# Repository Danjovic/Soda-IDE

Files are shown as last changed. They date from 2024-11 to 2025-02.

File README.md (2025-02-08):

# SODA IDE
Compact Flash Card Interface for MSX based on [SC729 RCBus Compact Flash Module]( https://smallcomputercentral.com/sc729-rcbus-compact-flash-module/) originally designed by [Tadeusz Pycio](http://www.vtsys.pl/interface-compact-flash/) and [Beer IDE 232](https://github.com/b3rendsh/msxdos2s) by b3rendsh 

## Printed circuit Boards:
### For Konami Case

#### Version 1
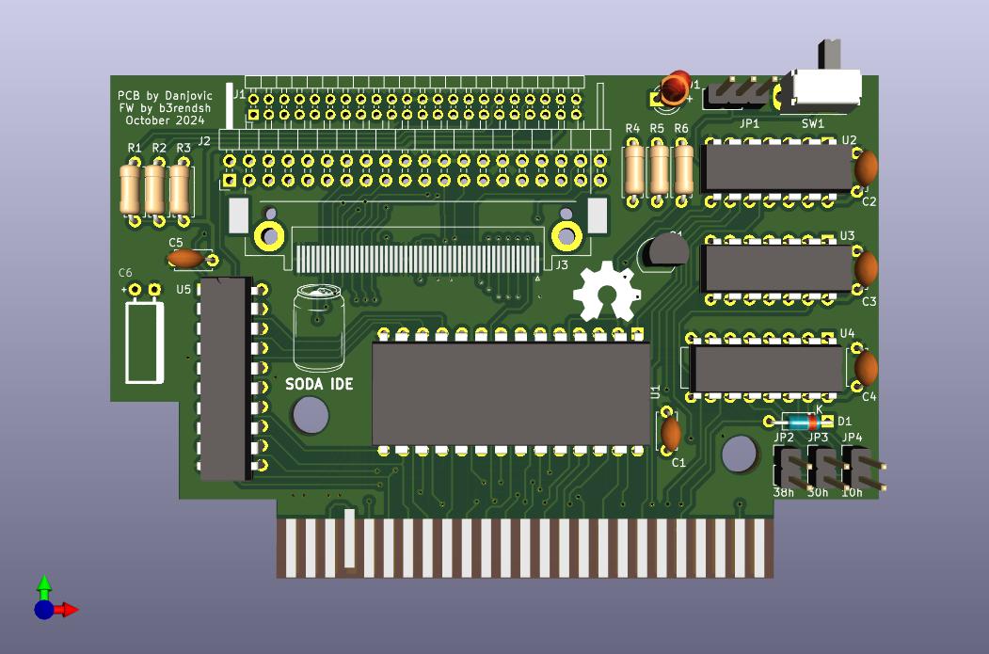
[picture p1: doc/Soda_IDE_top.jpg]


#### Version 2
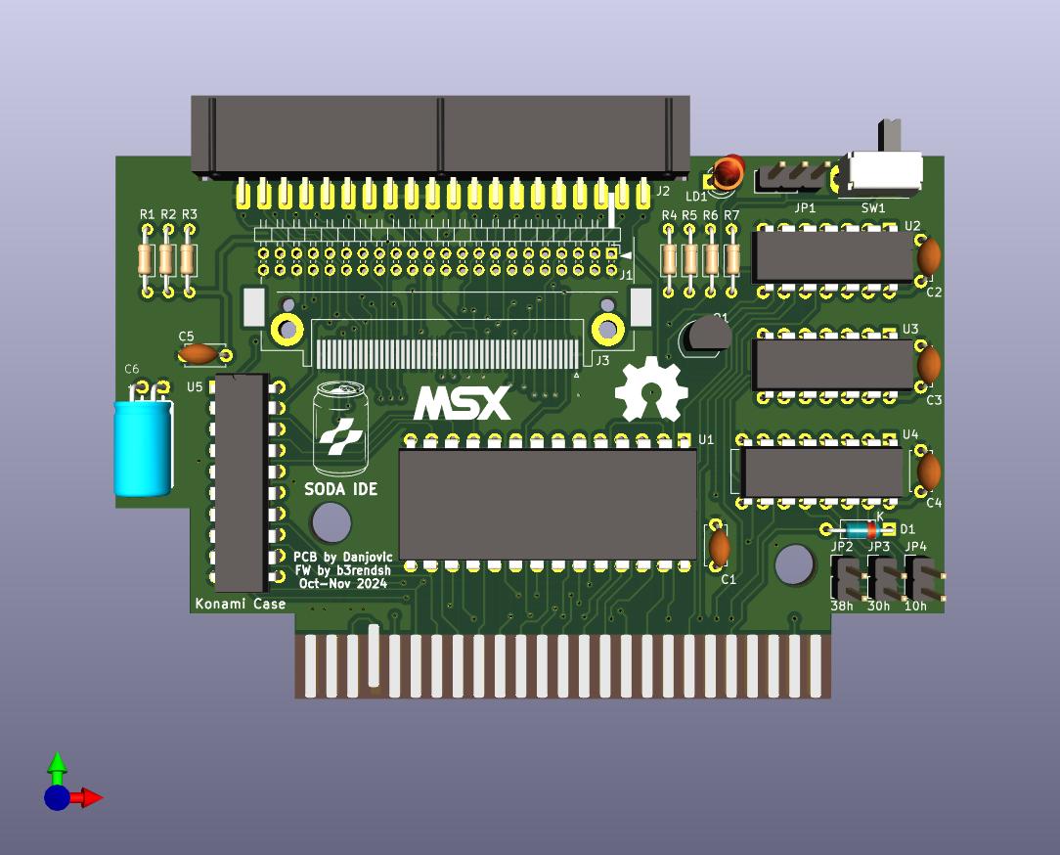
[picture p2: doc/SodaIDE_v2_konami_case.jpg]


### For Patola Case
#### Version 2
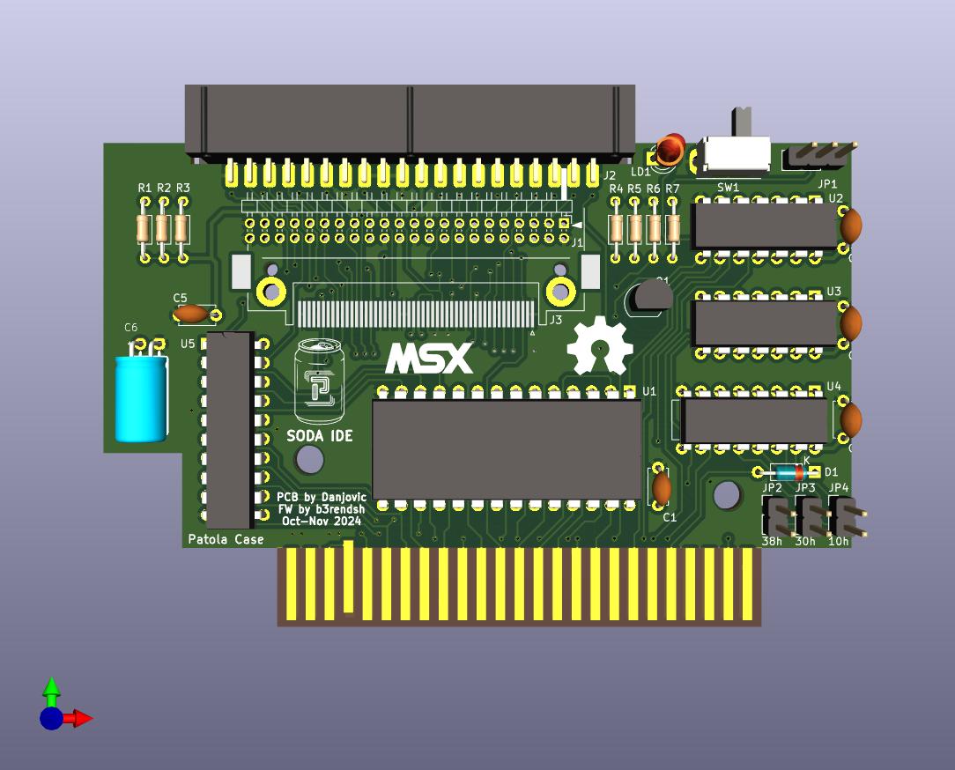
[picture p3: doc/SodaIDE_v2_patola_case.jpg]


### BILL OF MATERIALS

#### Semiconductors

| Reference | Value | Description |
|:---:|:---: |:--- |
|  U1 | 27C512 | EEPROM 64Kb x 8 (512kbits) |
|  U2 | 74HCT32  | TTL chip, can be either LS, HC or HCT |
|  U3 | 74HCT74  | TTL chip, can be either LS, HC or HCT |
|  U4 | 74HCT138 | TTL chip, can be either LS, HC or HCT |
|  U5 | 74HC245  | TTL chip, can be either LS, HC or HCT |
|  Q1 | BC548 | NPN transistor |
| LD1 | -- | Diameter 3.0mm, Red |
|  D1 | 1N4148 | Fast diode, Sillicon (alternatives 1N914) |

#### Capacitors

| Reference | Value | Description |
|:---:|:---: |:--- |
|C1,C2,C3,C4,C5| 100nF | Capacitor, Ceramic disc or Polyester |
|C6| 100uF/16V | Electrolytic Capacitor (preferrable low profile) |
		
#### Resistors		
| Reference | Value | Description |
|:---:|:---: |:--- |
| R1,R2,R3,R6 | 4K7 | Resistor, ¼ Watt | 
| R4 | 1K | Resistor, ¼ Watt | 
| R5 | 10K | Resistor, ¼ Watt | 
		
#### Miscellaneous		
| Reference | Value | Description |
|:---:|:---: |:--- |
|SW1	| -- | SPDT Switch, slide, right angle (reference OS102011MA1QN1) |
|CN1	| -- | Printed Circuit Board. Gerbers for Konami [V1](https://github.com/Danjovic/Soda-IDE/tree/main/hardware/V1/Gerber), [V2](https://github.com/Danjovic/Soda-IDE/tree/main/hardware/V2/SodaIDE_v2_konami_case/pcbway_production/2025-02-08-15-33-09), Patola [V2](https://github.com/Danjovic/Soda-IDE/tree/main/hardware/V2/SodaIDE_v2_patola_case/pcbway_production/2025-02-08-15-50-29) |
|JP1	| -- | Pin Header, 1x3 pin, pitch 2.54mm, straight (Vertical) |
|JP2,JP3,JP4 | -- | Pin Header, 1x2 pin, pitch 2.54mm, straight (Vertical) |

#### 44 pin CF adapter option		
| J1	|	Pin Header, 2x22 pin, pitch 2.0mm, right angle (Horizontal) |
|:---:| :--- |
		
#### 40 pin CF adapter option		
|J2	|	Pin Header, 2x20 pin, pitch 2.54mm, right angle (Horizontal)
|:---:| :--- |
		
#### CF Socket Option		
|J3	|	CF Card Connector (reference 3M_N7E50-E516xx-30)
|:---:| :--- |

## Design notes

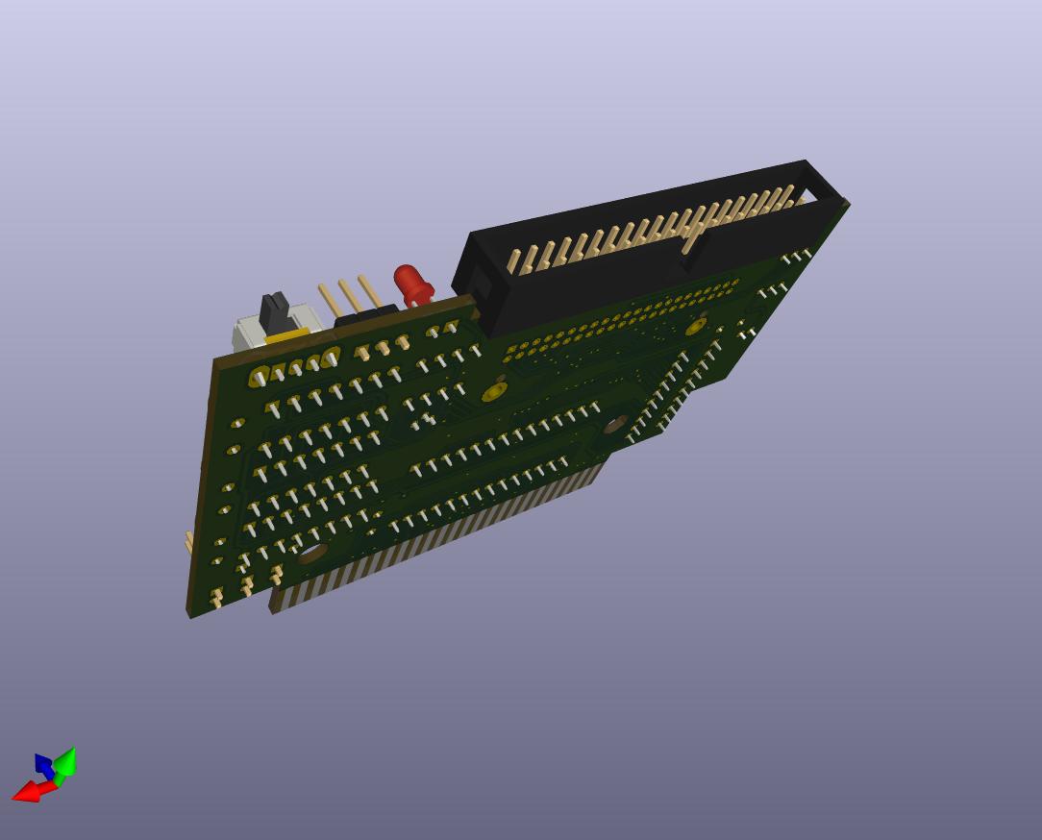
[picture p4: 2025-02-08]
doc/SodaIDE_v2_konami_case_rear.jpg

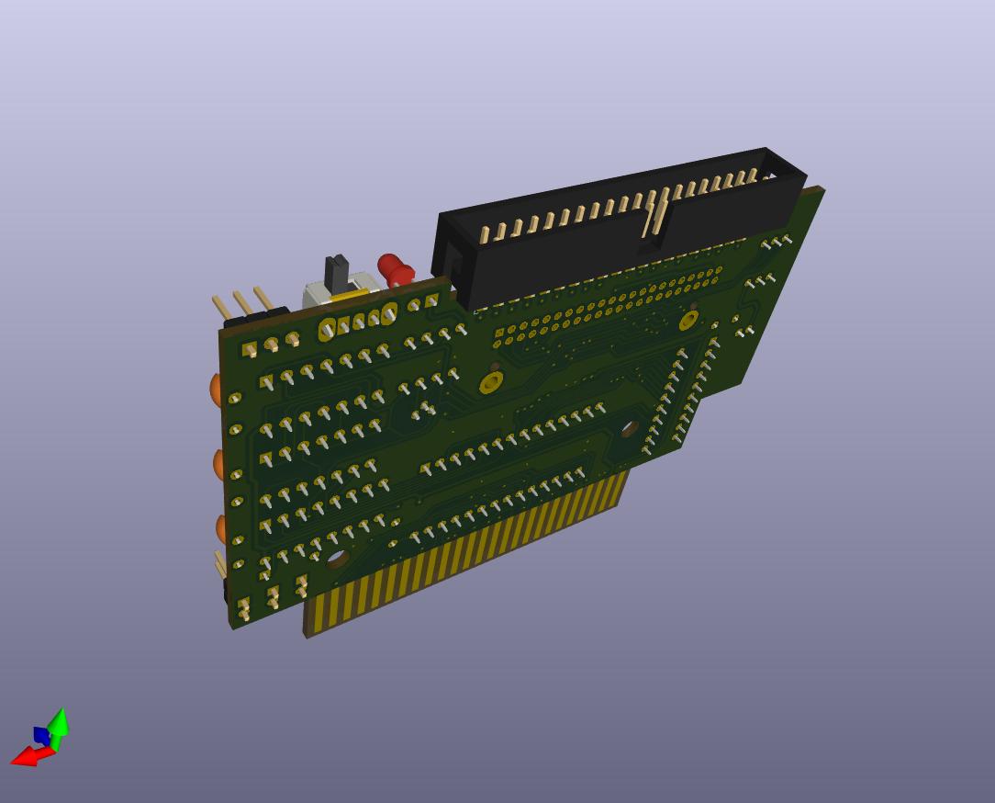
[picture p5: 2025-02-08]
doc/SodaIDE_v2_patola_case_rear.jpg

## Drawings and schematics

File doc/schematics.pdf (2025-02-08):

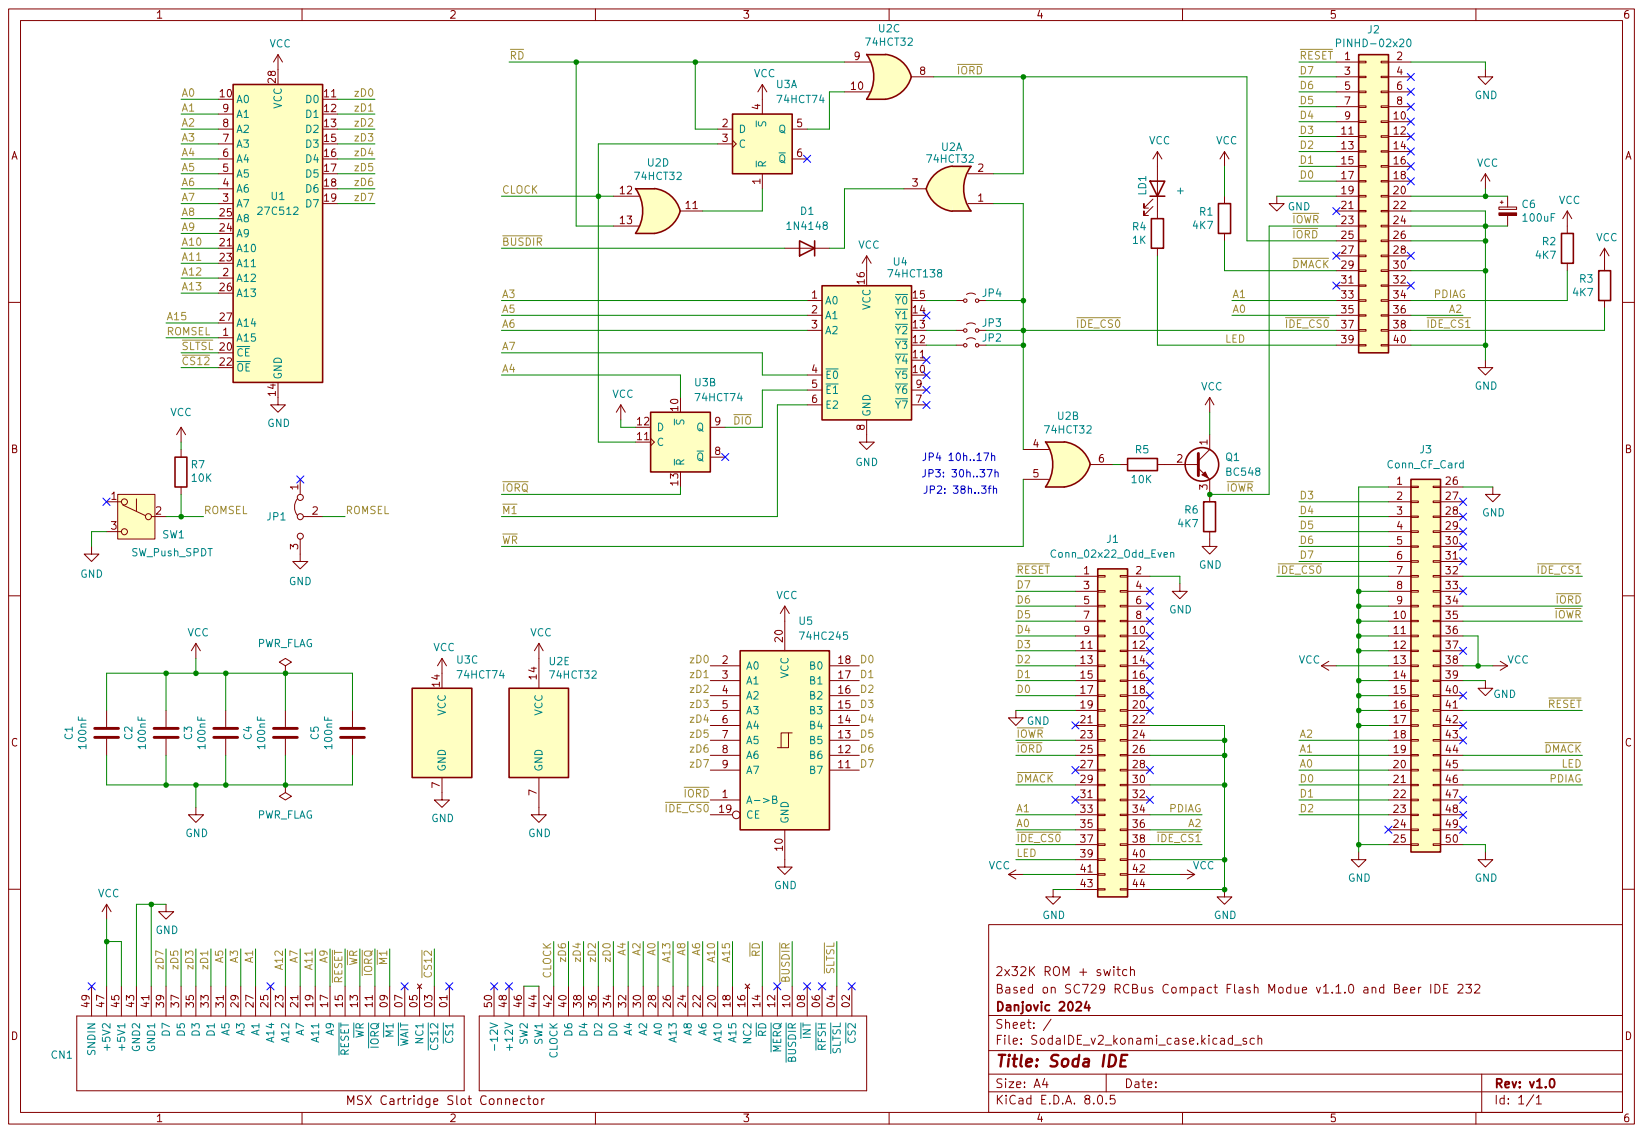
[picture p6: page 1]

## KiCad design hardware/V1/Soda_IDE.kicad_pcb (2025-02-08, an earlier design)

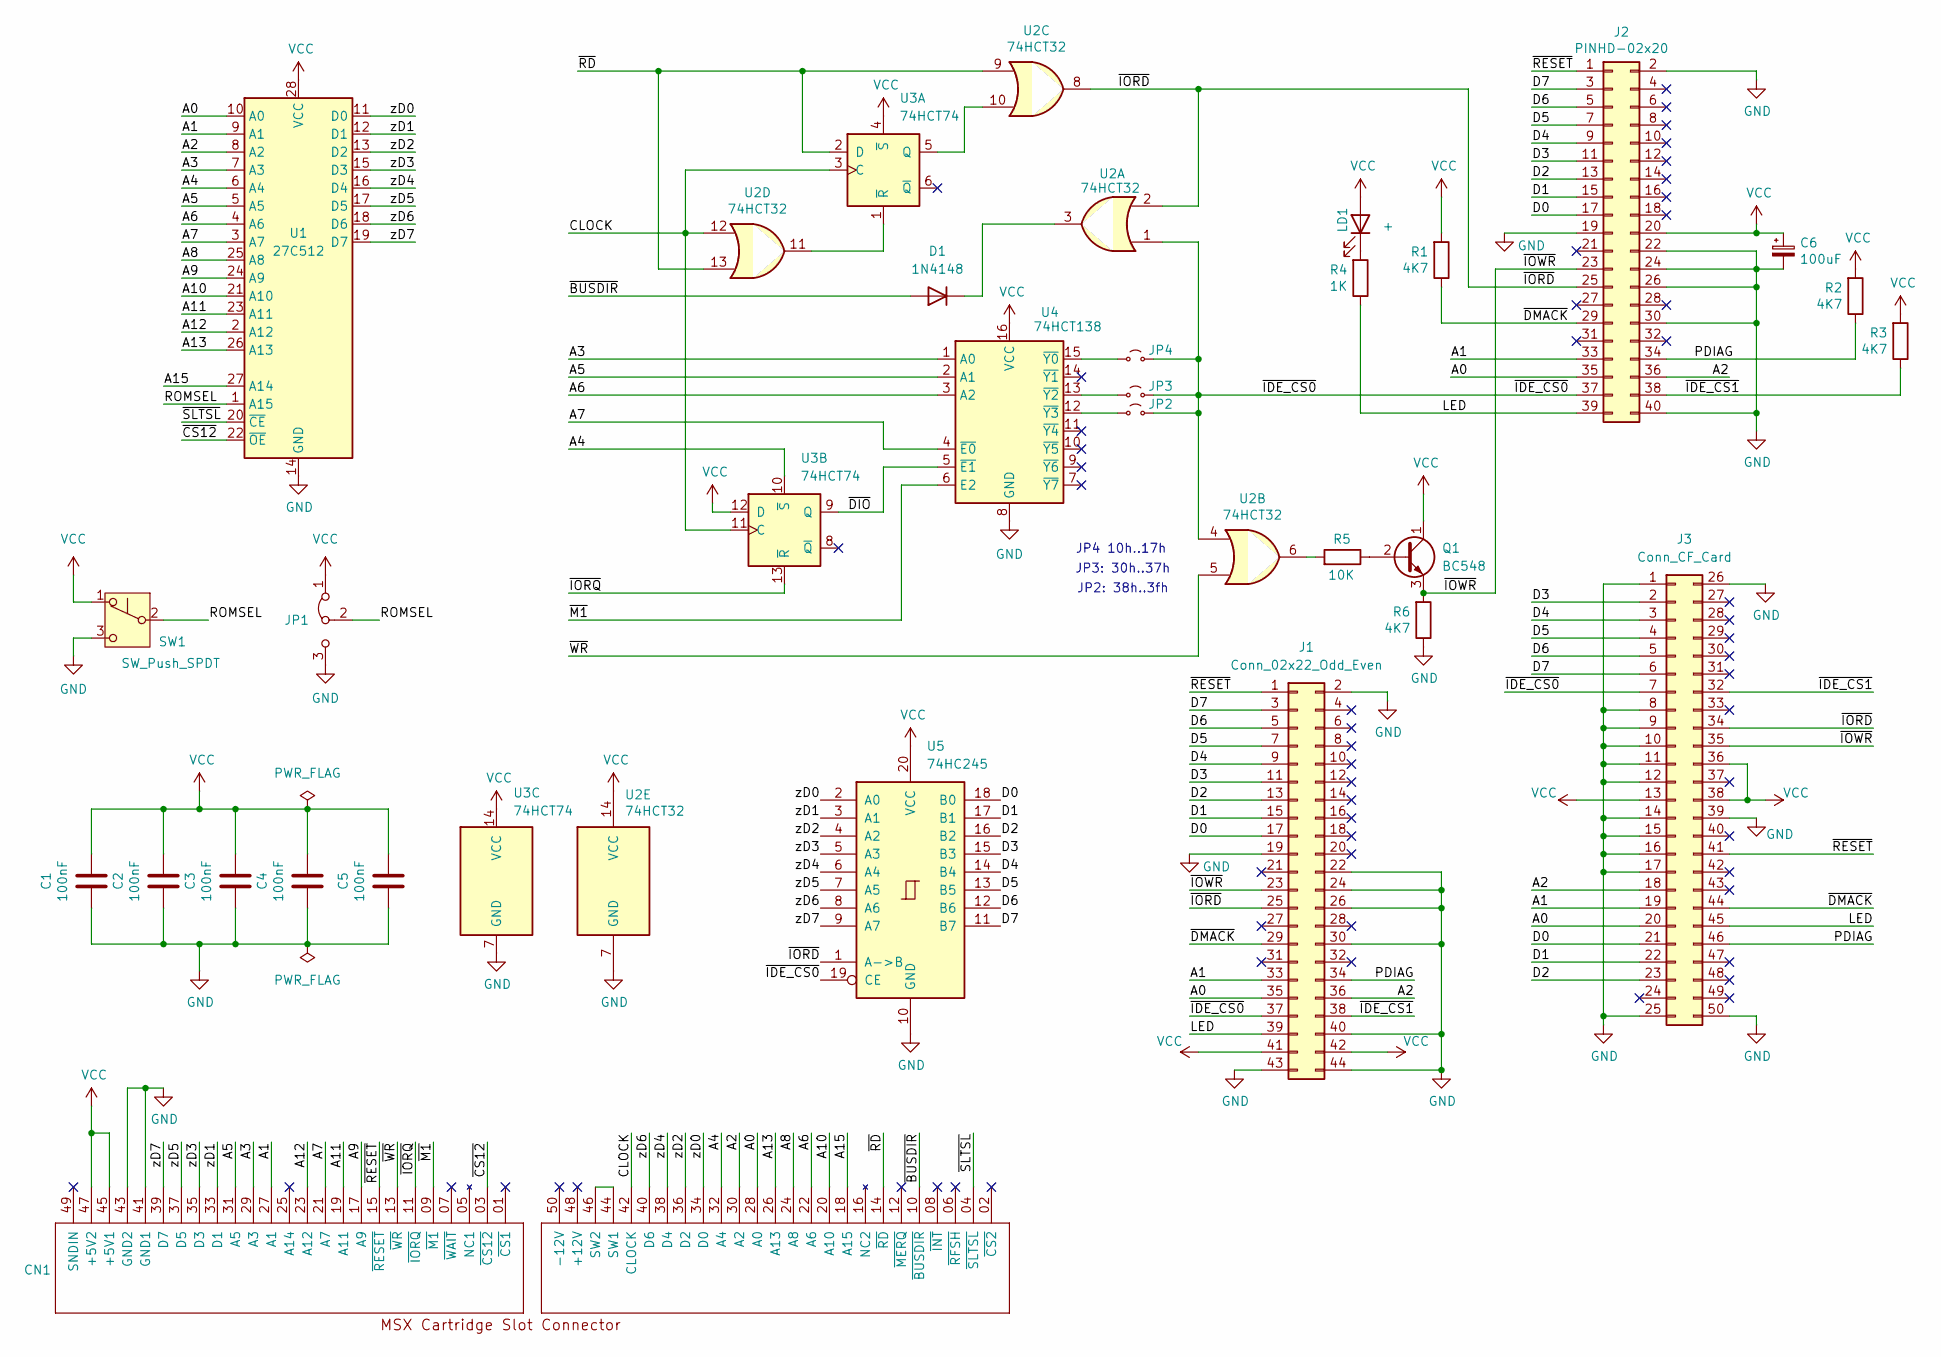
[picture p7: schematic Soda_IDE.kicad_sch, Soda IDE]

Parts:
C1, C2, C3, C4, C5: 100nF; C_Disc_D4.7mm_W2.5mm_P5.00mm
C6: 100uF; CP_lying
CN1: MSX_SLOT_CON; Cart_Konami
D1: 1N4148; D_DO-35_SOD27_P7.62mm_Horizontal
J1: Conn_02x22_Odd_Even; PinHeader_2x22_P2.00mm_Horizontal
J2: PINHD-02x20; PinHeader_2x20_P2.54mm_Horizontal
J3: Conn_CF_Card; CF-Card_3M_N7E50-E516xx-30
JP1: PIN_1x3; PinHeader_1x03_P2.54mm_Vertical
JP2, JP3, JP4: Jumper_2_Small_Open; PinHeader_1x02_P2.54mm_Vertical
LD1: +; LED_D3.0mm
Q1: BC548; TO-92_Inline
R1, R2, R3, R6: 4K7; R_Axial_DIN0207_L6.3mm_D2.5mm_P7.62mm_Horizontal
R4: 1K; R_Axial_DIN0207_L6.3mm_D2.5mm_P7.62mm_Horizontal
R5: 10K; R_Axial_DIN0207_L6.3mm_D2.5mm_P7.62mm_Horizontal
SW1: SW_Push_SPDT; SW_Slide_SPDT_Angled_CK_OS102011MA1Q
U1: 27C512; DIP-28_W15.24mm
U2: 74HCT32; DIP-14_W7.62mm
U3: 74HCT74; DIP-14_W7.62mm
U4: 74HCT138; DIP-16_W7.62mm
U5: 74HC245; DIP-20_W7.62mm

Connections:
/A0: CN1.28 (A0), J1.35, J2.35, J3.20, U1.10 (A0)
/A1: CN1.27 (A1), J1.33, J2.33, J3.19, U1.9 (A1)
/A2: CN1.30 (A2), J1.36, J2.36, J3.18, U1.8 (A2)
/A3: CN1.29 (A3), U1.7 (A3), U4.1 (A0)
/A4: CN1.32 (A4), U1.6 (A4), U3.10 (~S)
/A5: CN1.31 (A5), U1.5 (A5), U4.2 (A1)
/A6: CN1.22 (A6), U1.4 (A6), U4.3 (A2)
/A7: CN1.21 (A7), U1.3 (A7), U4.4 (~E0)
/A8: CN1.24 (A8), U1.25 (A8)
/A9: CN1.17 (A9), U1.24 (A9)
/A10: CN1.20 (A10), U1.21 (A10)
/A11: CN1.19 (A11), U1.23 (A11)
/A12: CN1.23 (A12), U1.2 (A12)
/A13: CN1.26 (A13), U1.26 (A13)
/A15: CN1.18 (A15), U1.27 (A14)
/CLOCK: CN1.42 (CLOCK), U2.12, U3.3 (C), U3.11 (C)
/D0: J1.17, J2.17, J3.21, U5.18 (B0)
/D1: J1.15, J2.15, J3.22, U5.17 (B1)
/D2: J1.13, J2.13, J3.23, U5.16 (B2)
/D3: J1.11, J2.11, J3.2, U5.15 (B3)
/D4: J1.9, J2.9, J3.3, U5.14 (B4)
/D5: J1.7, J2.7, J3.4, U5.13 (B5)
/D6: J1.5, J2.5, J3.5, U5.12 (B6)
/D7: J1.3, J2.3, J3.6, U5.11 (B7)
/LED: J1.39, J2.39, J3.45, R4.1
/PDIAG: J1.34, J2.34, J3.46, R2.1
/ROMSEL: JP1.2 (C), SW1.2 (B), U1.1 (A15)
/zD0: CN1.34 (D0), U1.11 (D0), U5.2 (A0)
/zD1: CN1.33 (D1), U1.12 (D1), U5.3 (A1)
/zD2: CN1.36 (D2), U1.13 (D2), U5.4 (A2)
/zD3: CN1.35 (D3), U1.15 (D3), U5.5 (A3)
/zD4: CN1.38 (D4), U1.16 (D4), U5.6 (A4)
/zD5: CN1.37 (D5), U1.17 (D5), U5.7 (A5)
/zD6: CN1.40 (D6), U1.18 (D6), U5.8 (A6)
/zD7: CN1.39 (D7), U1.19 (D7), U5.9 (A7)
/~BUSDIR: CN1.10 (~BUSDIR), D1.2 (A)
/~CS12: CN1.03 (~CS12), U1.22 (~OE)
/~DIO: U3.9 (Q), U4.5 (~E1)
/~DMACK: J1.29, J2.29, J3.44, R1.1
/~IDE_CS0: J1.37, J2.37, J3.7, JP2.2 (B), JP3.2 (B), JP4.2 (B), U2.1, U2.4, U5.19 (CE)
/~IDE_CS1: J1.38, J2.38, J3.32, R3.1
/~IORD: J1.25, J2.25, J3.34, U2.2, U2.8, U5.1 (A->B)
/~IORQ: CN1.11 (~IORQ), U3.13 (~R)
/~IOWR: J1.23, J2.23, J3.35, Q1.3 (E), R6.2
/~M1: CN1.09 (~M1), U4.6 (E2)
/~RD: CN1.14 (~RD), U2.9, U2.13, U3.2 (D)
/~RESET: CN1.15 (~RESET), J1.1, J2.1, J3.41
/~SLTSL: CN1.04 (~SLTSL), U1.20 (~CE)
/~WR: CN1.13 (~WR), U2.5
GND: C1.2, C2.2, C3.2, C4.2, C5.2, C6.2, CN1.41 (GND1), CN1.43 (GND2), J1.2, J1.19, J1.22, J1.24, J1.26, J1.30, J1.40, J1.43, J1.44, J2.2, J2.19, J2.22, J2.24, J2.26, J2.30, J2.40, J3.1, J3.8, J3.9, J3.10, J3.11, J3.12, J3.14, J3.15, J3.16, J3.17, J3.25, J3.26, J3.39, J3.50, JP1.3 (B), R6.1, SW1.3 (C), U1.14 (GND), U2.7 (GND), U3.7 (GND), U4.8 (GND), U5.10 (GND)
unnamed: CN1.44 (SW1), CN1.46 (SW2)
unnamed: D1.1 (K), U2.3
unnamed: JP2.1 (A), U4.12 (~Y3)
unnamed: JP3.1 (A), U4.13 (~Y2)
unnamed: JP4.1 (A), U4.15 (~Y0)
unnamed: LD1.1 (K), R4.2
unnamed: Q1.2 (B), R5.1
unnamed: R5.2, U2.6
unnamed: U2.10, U3.5 (Q)
unnamed: U2.11, U3.1 (~R)
VCC: C1.1, C2.1, C3.1, C4.1, C5.1, C6.1, CN1.45 (+5V1), CN1.47 (+5V2), J1.41, J1.42, J2.20, J3.13, J3.36, J3.38, JP1.1 (A), LD1.2 (A), Q1.1 (C), R1.2, R2.2, R3.2, SW1.1 (A), U1.28 (VCC), U2.14 (VCC), U3.4 (~S), U3.12 (D), U3.14 (VCC), U4.16 (VCC), U5.20 (VCC)

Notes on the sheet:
JP4 10h..17h
JP3: 30h..37h
JP2: 38h..3fh

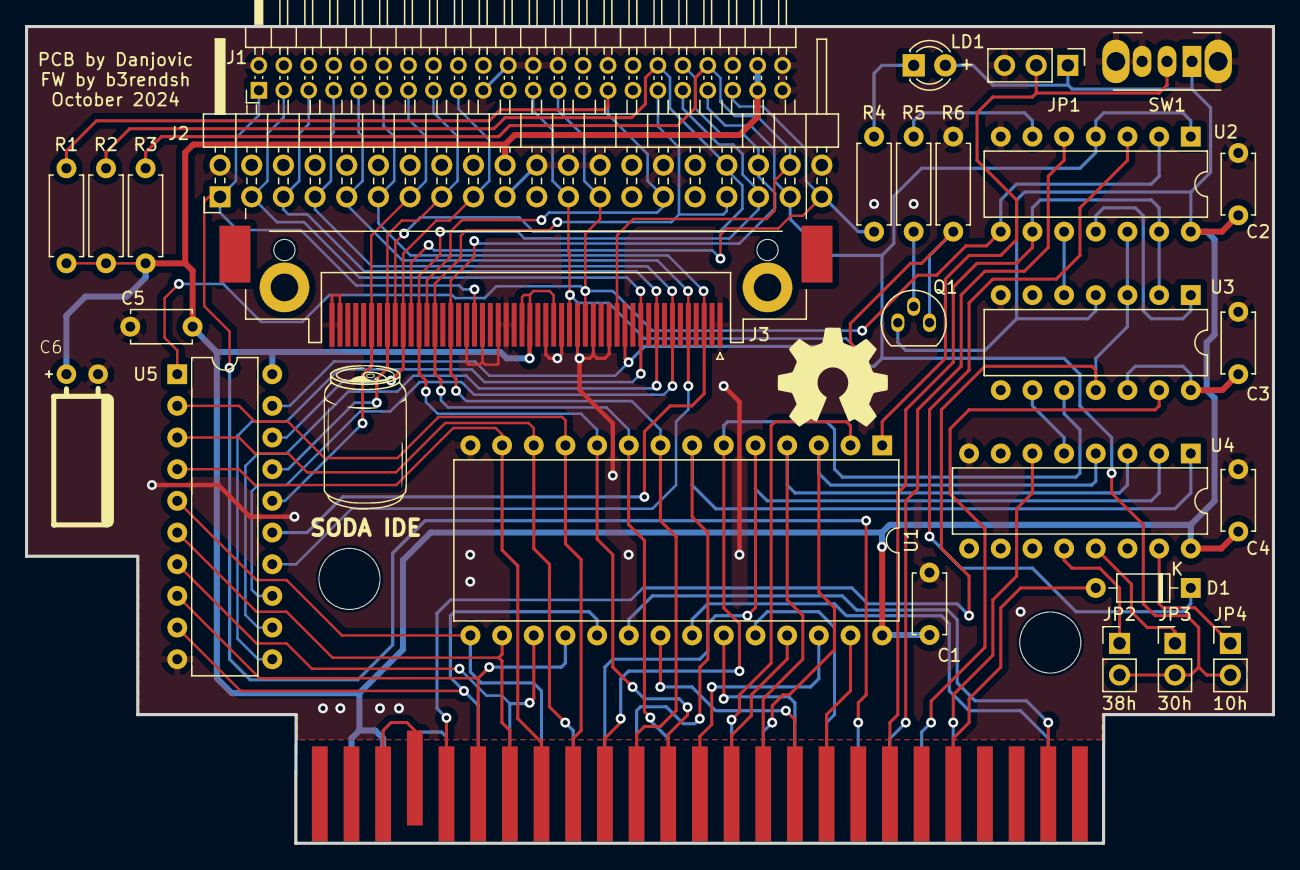
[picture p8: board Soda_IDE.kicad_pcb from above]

Board: 2 copper layers, 100.0 x 65.5 mm, 29 parts (0 on the bottom side), 61 nets.

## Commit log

2024-10-25 fixes and updates
    [Soda_IDE.kicad_pcb, Soda_IDE.kicad_sch]
2024-10-25 conventional jumpers for address selection
    [Soda_IDE.kicad_pcb, Soda_IDE.kicad_sch]
2024-10-29 Added buffer to data lines
    [Soda_IDE.kicad_pcb, Soda_IDE.kicad_sch]
2024-10-30 updated board
    [Soda_IDE.kicad_pcb, Soda_IDE.kicad_sch]
2024-11-07 Reduced board width to be within 100mm
    [Soda_IDE.kicad_pcb]
2025-02-08 New boards for Konami and Patola cases
    [SodaIDE_v2_konami_case.kicad_pcb, SodaIDE_v2_konami_case.kicad_sch, SodaIDE_v2_patola_case.kicad_pcb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]
